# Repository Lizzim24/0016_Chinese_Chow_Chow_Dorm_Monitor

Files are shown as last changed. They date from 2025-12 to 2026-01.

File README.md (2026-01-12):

# Chinese Chow Chow Dorm Monitor

<p align="center">
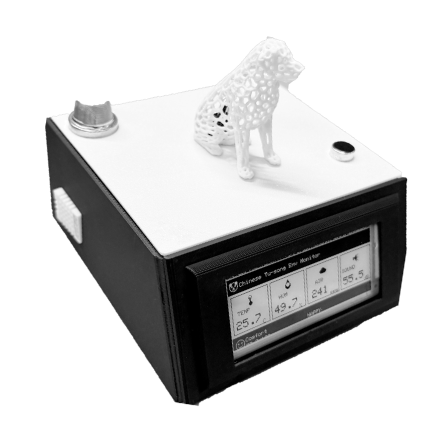
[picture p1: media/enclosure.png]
  <br>
  <em>Figure 1. The 3D-printed enclosure</em>
</p>

A biologically-informed IoT monitoring system designed for “Tu-song,” a Chow Chow living in a small student dormitory environment.  
The system monitors temperature, humidity, gases, and noise and computes a **breed-specific Comfort Index (CI)** for welfare assessment.

---

## 🐶 Why Chow Chow? Why Dorms?

Environmental monitors are typically designed for **humans**, but high-density indoor living poses unique physiological stressors for non-human inhabitants—especially double-coated, partially brachycephalic dogs such as the Chow Chow.

Chow Chows have:

- Dense double coat → high thermal sensitivity  
- Partial brachycephaly → airway restrictions under heat/humidity  
- Acute hearing → noise sensitivity in dorms  
- Sensitive skin → humidity + ammonia risk  

This project reframes environmental sensing around **species-specific comfort thresholds**, rather than generic human metrics.

---

## 🎯 Project Objectives

- Monitor key dorm environment variables  
- Map raw sensor data to a Comfort Index (CI)  
- Provide real-time feedback via LED + E-Paper  
- Detect hazard events (VOC, ammonia, noise spikes)  

---

## 🧩 System Architecture
<p align="center">
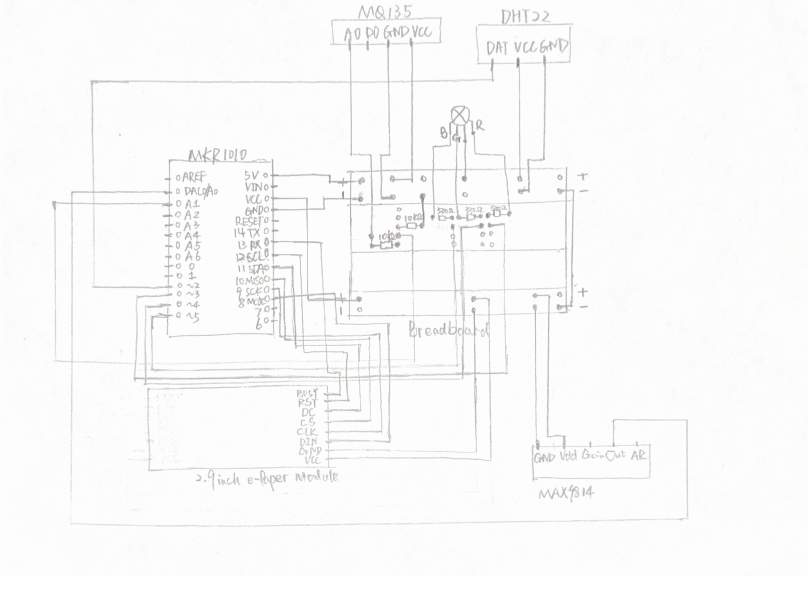
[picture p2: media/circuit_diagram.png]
  <br>
  <em>Figure 2. The whole circuit diagram. </em>
</p>
<p align="center">
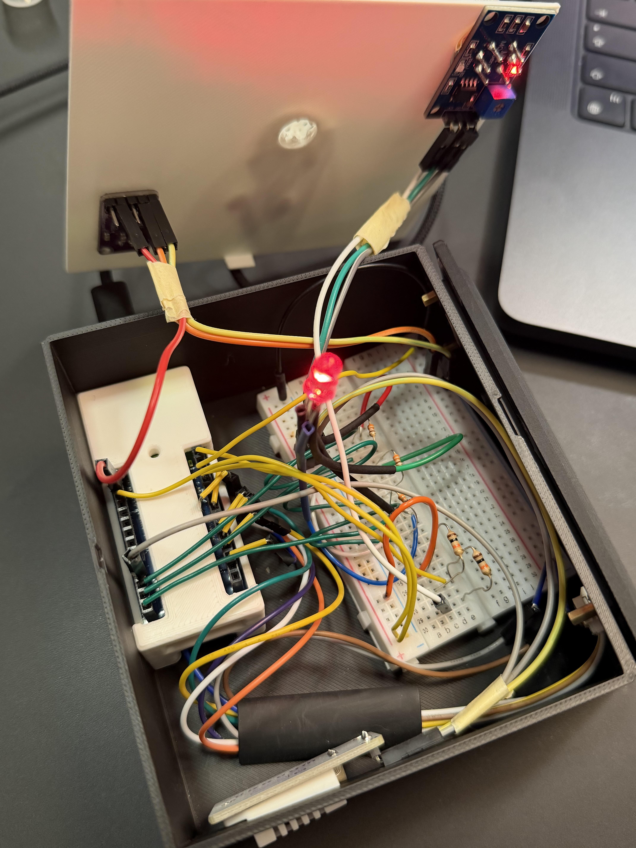
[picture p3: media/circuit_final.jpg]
  <br>
  <em>Figure 3. The actual circuit diagram. </em>
</p>

### Sensors & Biological Rationale

| Sensor | Parameter | Reason (Breed-Specific) |
| --- | --- | --- |
| DHT22 | Temp + Humidity | Thermal & skin sensitivity |
| MQ135 | VOC + Ammonia | Pet hygiene + respiratory irritation |
| MAX9814 | Noise level | Stress & acoustic sensitivity |
| E-Paper | Visual feedback | Zero light disturbance for the dog |
| MKR1010 | MCU + WiFi | Compute CI + future networking capability |

---

## 🔌 Hardware Design

- **MCU:** Arduino MKR WiFi 1010  
- **Gas:** MQ135 (5V) + voltage divider → 3.3V logic safe  
- **Acoustic:** MAX9814 w/ Auto Gain Control (AGC)  
- **Thermal:** DHT22 ±0.5 °C  
- **Display:** 2.9" E-Paper  
- **LED Feedback:** RGB real-time indicator  
- **Resistor:** Three 330Ω Resistors and two 10kΩ Resistors

Voltage protection implemented via:

$$ float voltage = (raw / 4095.0) * 3.3 * 2.0; $$

---

## 🧠 Comfort Index (CI) Model

The originality lies in the interpretive algorithm, not the raw sensing.

$$CI = 0.3·Temp + 0.3·Humidity + 0.2·Air + 0.2·Noise$$

Each dimension uses a trapezoidal mapping, for example:

- Optimal Zone (e.g., 15–22 °C) → score = 100  
- Warning Zone → linearly decreasing score  
- Danger Zone (e.g., > 28 °C) → score = 0

<p align="center">
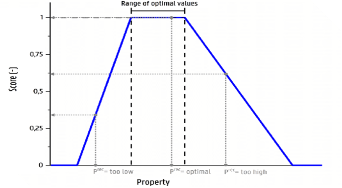
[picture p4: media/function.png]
  <br>
  <em>Figure 4. The trapezoidal mapping function.</em>
</p>
  
<p align="center">
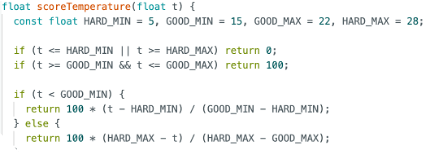
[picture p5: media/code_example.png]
  <br>
  <em>Figure 5. The temperature score code.</em>
</p>
---

## 🚨 Safety Override

A safety override loop runs independently of the 5-minute update cycle.

It triggers immediate alerts if:

- `NH₃ > 5 ppm` (from MQ135), or  
- `Noise > 75 dB` (from MAX9814)

When triggered:

- RGB LED is forced to **Red**  
- E-Paper display is forced to refresh  
- Critical hazards are shown even in low-power mode  

---

## 🖥 Dual Feedback Layers

### **1. Real-time RGB LED**
<p align="center">
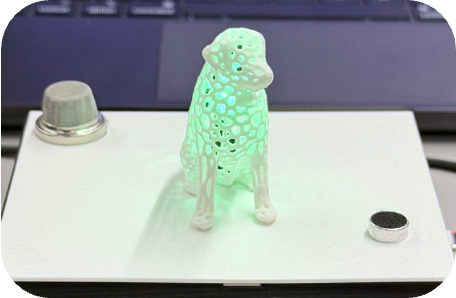
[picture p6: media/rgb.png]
  <br>
  <em>Figure 6. The RGB LED light.</em>
</p>

Color-coded welfare state:

- 🟢 Green — Comfortable & safe environment  
- 🟡 Yellow — Mild discomfort detected  
- 🔴 Red — Poor or hazardous environmental condition  

Includes:

- Auto-sleep logic to reduce disturbance during night  
- Still respects safety override for critical alerts  

### **2. E-Paper Display**
<p align="center">
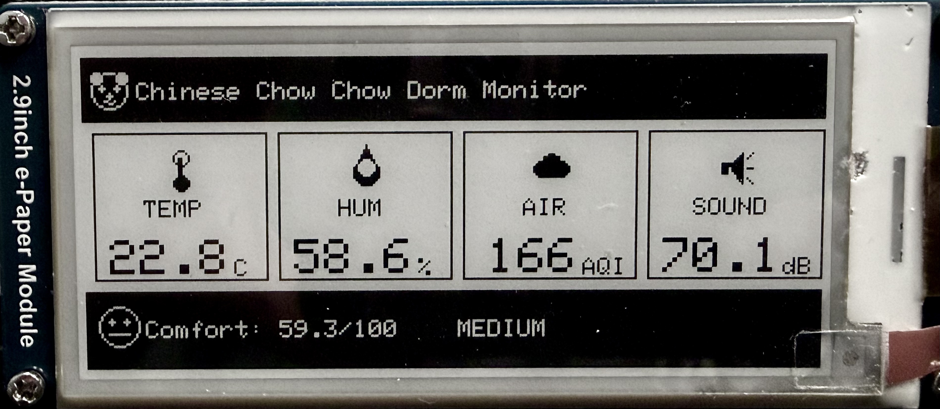
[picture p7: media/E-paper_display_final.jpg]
  <br>
  <em>Figure 7. The  e-paper interface.</em>
</p>

Hybrid refresh strategy:

- **Heartbeat Update:** Full refresh every 5 minutes  
- **Event-Triggered Update:** On significant changes  
  - e.g. Temp change > 0.5 °C, AQI change > 20  
- **Cooldown:** 30-second lockout to protect the screen  

This balances information freshness with power efficiency.

---

## 🏗 Physical Enclosure (Fusion 360)

<p align="center">
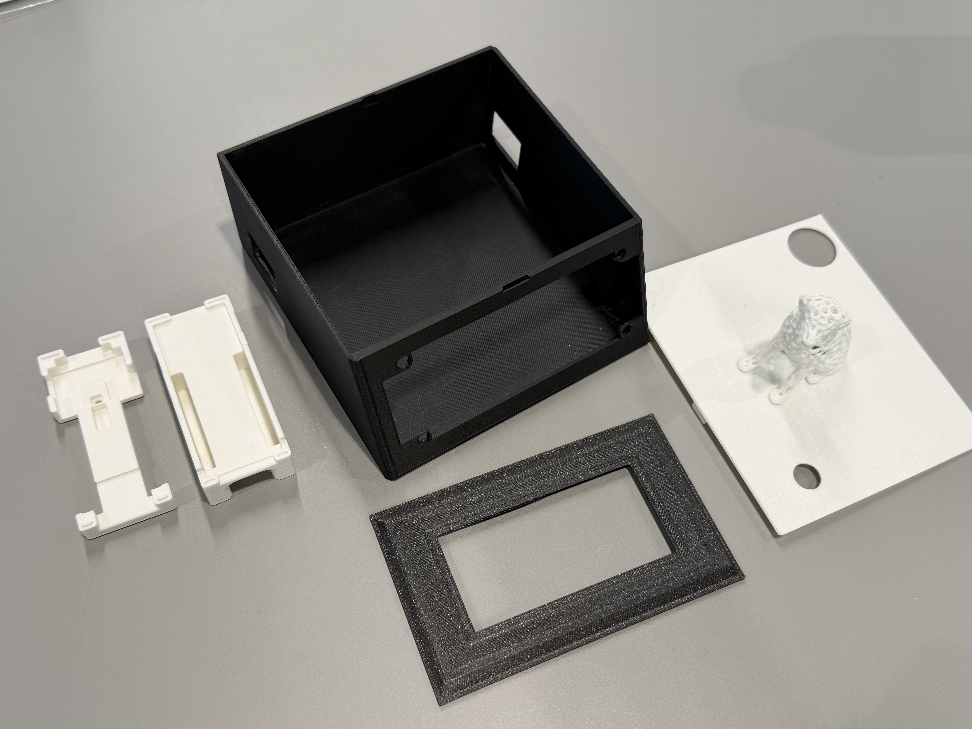
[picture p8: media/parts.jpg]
  <br>
  <em>Figure 8. All the parts of the enclosure design.</em>
</p>

The enclosure is designed with:

- Compact footprint suitable for a dorm room  
- Modular accessibility (removable top lid)  
- Dedicated cutouts for DHT22, MQ135, and MAX9814 so sensors can “see” the real environment  
- Front-facing E-Paper window for readability

<p align="center">
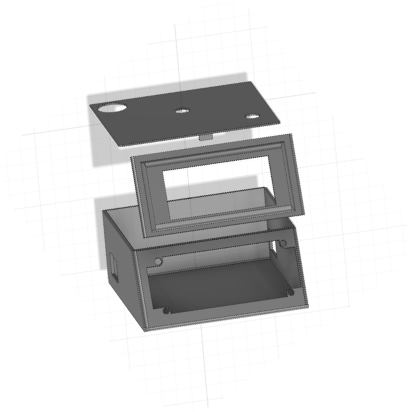
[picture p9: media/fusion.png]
  <br>
  <em>Figure 9. The parts that I designed.</em>
</p>

### **The Voronoi Dog Diffuser**

The visual centerpiece is a 3D-printed Voronoi Dog model (based on an open-source mesh by Kijai):

- The model is hollowed to house the RGB LED  
- The Voronoi pattern diffuses light into a soft glow  
- Avoids harsh LED glare and reduces light pollution at night
<p align="center">
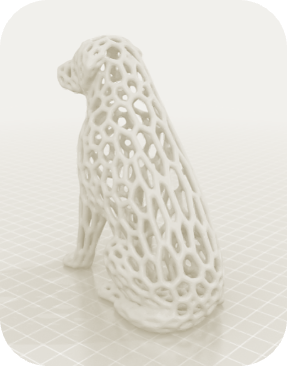
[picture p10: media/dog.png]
  <br>
  <em>Figure 10. The part that designed by Kijai.</em>
</p> 

### **The MKR 1010 Case**

- Portecting the arduino mkr wi-fi 1010 in my designed box.

<p align="center">
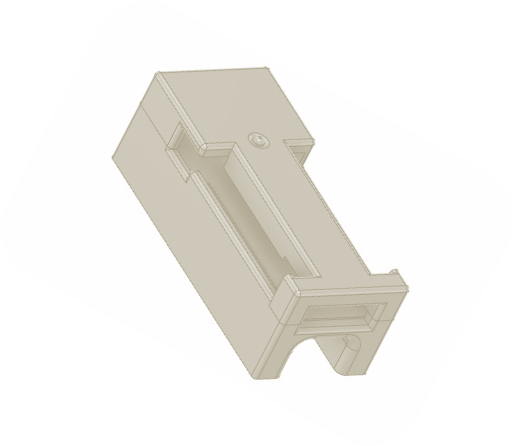
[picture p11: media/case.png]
  <br>
  <em>Figure 11. The part that designed by Piotr_W.</em>
</p> 
---

## 🧾 Evaluation

A 24-hour test in a ~20 m² student dorm showed:

- **14:00** – Direct sunlight raised temperature to ~25.5 °C → Yellow caution alert  
- **19:00** – Use of cleaning spray raised MQ135 reading to 256 ppm → Red “Dirty Air” alert  

These patterns suggest that:

- The CI mapping and thresholds respond realistically to dorm conditions  
- The system can detect and communicate real hazards relevant to a Chow Chow  

▶️ **Demo Video:** [https://youtu.be/xxxxxxx](https://youtu.be/MpVPKv-Cd-Y)

---

## ✅ Achievements & Limitations

### **Strengths**

- Breed-specific interpretation instead of generic “pet” logic  
- Trapezoidal Comfort Index algorithm implemented on MCU  
- E-Paper + Voronoi diffuser gives low-disturbance feedback  
- Custom Fusion 360 enclosure → functional + aesthetic  
- Thoughtful hardware protection (voltage divider, internal mounting)  

### **Limitations**

- MQ135 is an analog gas sensor → trend detection rather than absolute ppm accuracy  
- System is currently **monitor-only**; no active environmental control  
- MQ135 heater draws significant current → battery runtime constraints  

---

## 🚀 Future Roadmap

Planned/possible extensions:

- [ ] Add a relay-controlled fan for active ventilation  
- [ ] Integrate MQTT publishing and a remote Grafana dashboard  
- [ ] Introduce data logging for long-term comfort analysis  
- [ ] Explore CO₂ / NDIR sensors for better indoor air quality metrics  
- [ ] Power optimisation (duty-cycling, sensor sleep modes)  

---

## 🛠️ Tools & Technologies Used

### **Hardware & Prototyping**
- Arduino MKR WiFi 1010 (Cortex-M0+ MCU)
- DHT22 (Temperature & Humidity)
- MQ135 (VOC + Ammonia Gas Sensor)
- MAX9814 (AGC Microphone Module)
- 4-Pin RGB LED Indicator
- 2.9" E-Paper Display
- Breadboard + Jumper Wires + three 330Ω Resistors + two 10kΩ Resistors
- USB Power Supply

### **Software & Programming**
- Arduino IDE (Embedded C++)
- GxEPD2 (E-Paper Display Library)
- DHT Sensor Library
- Analog Signal Processing (MAX9814)
- Trapezoidal Mapping Algorithm (Custom)
- Safety Override Logic (Custom)

### **CAD & Manufacturing**
- Autodesk Fusion 360 (3D Design)
- FDM 3D Printing (Enclosure)
- PLA Filament (White & Black)
- Fusion STL Export → Slicing Pipeline

## 📚 References

- American Kennel Club (AKC) (2023) Chow Chow Dog Breed Information. Available at: https://www.akc.org/dog-breeds/chow-chow/ (Accessed: 10 January 2026).
- Analog Devices (n.d.) MAX9814: Microphone Amplifier with AGC and Low-Noise Microphone Bias. Available at: https://www.analog.com/media/en/technical- documentation/data-sheets/max9814.pdf (Accessed: 10 January 2026).
- Aosong Electronics (n.d.) Digital-output relative humidity & temperature sensor/module AM2302. Available at: https://www.mouser.com/datasheet/2/737/dht- 932870.pdf (Accessed: 5 January 2026).
- Arduino (2025) Arduino MKR Wi-Fi 1010 Documentation. Available at: https://docs.arduino.cc/hardware/mkr-wifi-1010/ (Accessed: 5 January 2026)
- Kijai (2021) Voronoi Dog. Available at: https://www.thingiverse.com/thing:4792489 (Accessed: 10 January 2026).
- Piotr_W (2021) Arduino MKR Wi-Fi 1010 case. Available at: https://www.thingiverse.com/thing:4818736 (Accessed: 10 January 2026).
- Waveshare (n.d.) 2.9inch e-Paper Datasheet. Available at: https://www.waveshare.com/wiki/File:2.9inch_e-Paper_Datasheet.pdf (Accessed: 10 January 2026).
- Winsen Sensor (2015) MQ135 Semiconductor Sensor for Hazardous Gas (Ver1.4). Available at: https://www.winsen-sensor.com/d/files/PDF/Semiconductor%20Gas%20Sensor/MQ135%20(Ver1.4)%20-%20Manual.pdf (Accessed: 10 January 2026).

## 🤖 Generative AI Use

This project used Generative AI tools (e.g. ChatGPT/Claude) in a supporting role for:

- Polishing English text (e.g. report sections, README)
- Translating mathematical ideas (trapezoidal mapping) into C++ pseudocode
- High-level debugging hints for Arduino libraries

All code and design decisions were:

- Manually validated against official datasheets
- Tested on hardware
- Owned and adapted by the author

The core concept, Comfort Index design, Fusion 360 enclosure, and full implementation were created by the author.

---
Personal Coursework for CASA0016 by Lizi

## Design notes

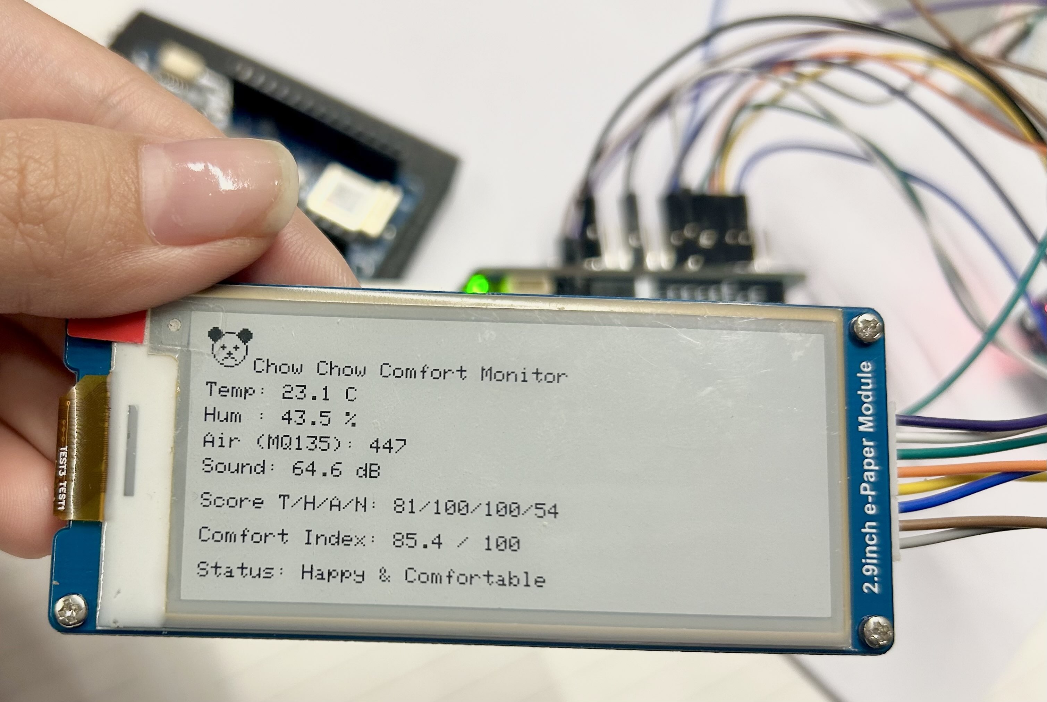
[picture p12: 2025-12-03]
media/E-paper_display_v1.jpg

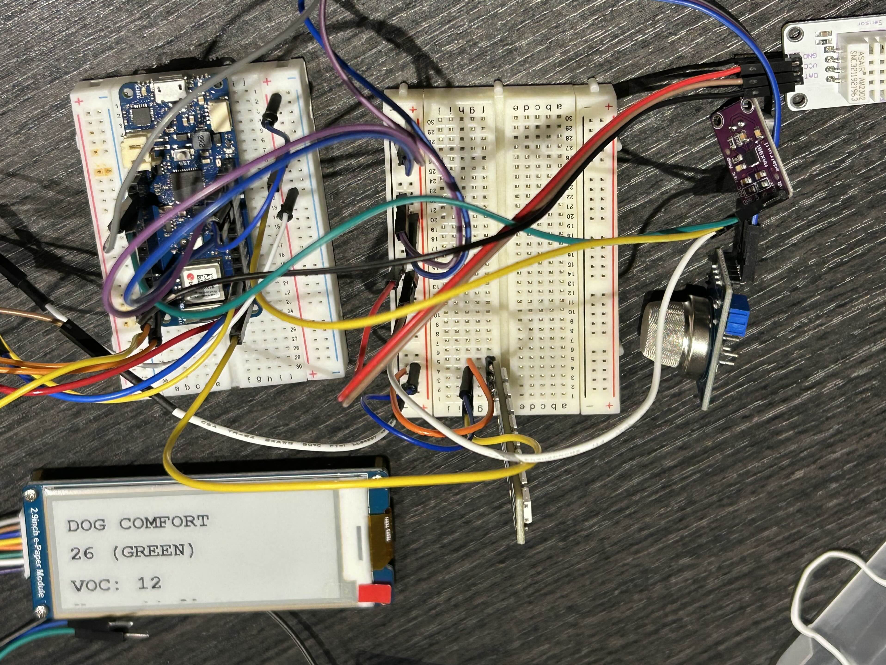
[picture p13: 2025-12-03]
media/circuit-v1.jpg

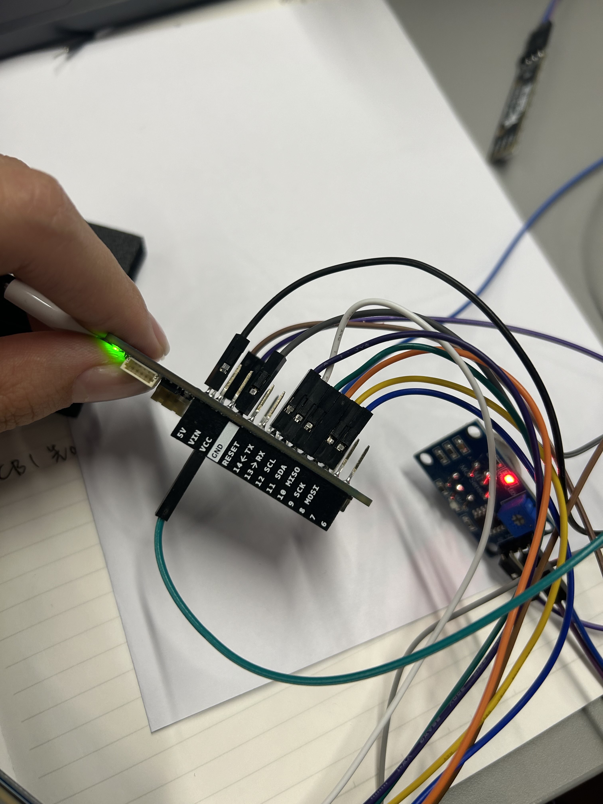
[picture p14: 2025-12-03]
media/circuit-v2.1.jpg

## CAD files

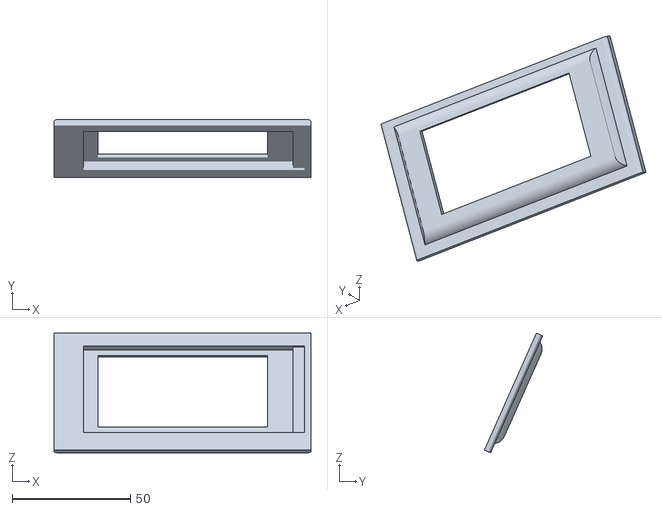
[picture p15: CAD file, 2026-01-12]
3D_model/mypj_cover.stl
108.6 x 24.7 x 50.6

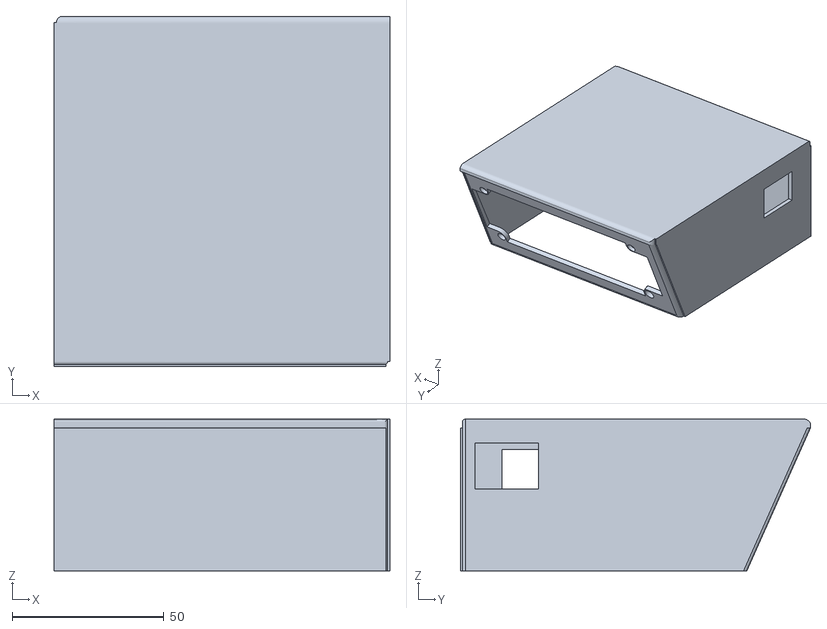
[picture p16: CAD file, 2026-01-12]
3D_model/mypj_v2botttom.stl
110.6 x 115.3 x 50.0

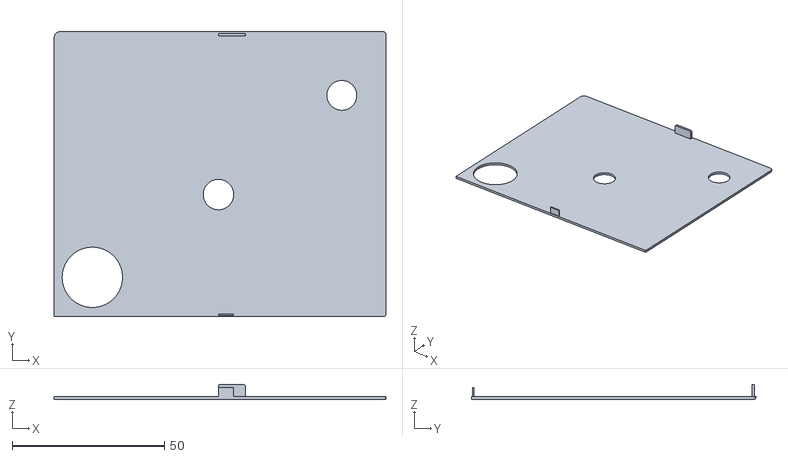
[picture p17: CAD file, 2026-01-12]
3D_model/mypj_v2lid.stl
109.0 x 93.5 x 5.00

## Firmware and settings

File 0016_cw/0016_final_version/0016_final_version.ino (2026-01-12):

#include "DHT.h"
#include <GxEPD2_BW.h>
#include <Adafruit_GFX.h>
#include <math.h>

#define PIN_MQ135 A1
#define PIN_SOUND A0
#define PIN_DHT 2
#define PIN_LED_R 3
#define PIN_LED_G 4
#define PIN_LED_B 5

#define EPAPER_CS 10
#define EPAPER_DC 11
#define EPAPER_RST 12
#define EPAPER_BUSY 13

#define DHTTYPE DHT22
DHT dht(PIN_DHT, DHTTYPE);

#define LED_SLEEP_AFTER_MS 30000UL
#define LED_MAX_VAL 200

const int RAW_QUIET = 1380;
const int RAW_LOUD = 1800;
const float DB_QUIET = 35.0;
const float DB_LOUD = 80.0;

#define RL_VALUE 10.0           
#define RO_CLEAN_AIR_FACTOR 3.6  
float MQ135_RO = 10.0;          

GxEPD2_BW<GxEPD2_290_T94, GxEPD2_290_T94::HEIGHT> display(
  GxEPD2_290_T94(EPAPER_CS, EPAPER_DC, EPAPER_RST, EPAPER_BUSY));

struct AirQualityData {
  int rawValue;
  int aqi;           
  float co2_ppm;     
  float nh3_ppm;     
  float score;       
  const char *level; 
  const char *color; 
};


struct SensorData {
  float temp;
  float humidity;
  AirQualityData airQuality;  
  float soundDB;
  float last_dB;

  float tempScore;
  float humScore;
  float airScore;
  float noiseScore;
  float comfortIndex;

  float lastTemp;
  float lastHum;
  int lastAQI;
  float lastComfort;
};

SensorData sensor = { 0 };

unsigned long lastSensorRead = 0;
unsigned long lastLedActiveTime = 0;
unsigned long lastEpaperUpdate = 0;

const unsigned long SENSOR_INTERVAL = 2000;
const unsigned long EPAPER_INTERVAL = 300000;
const unsigned long EPAPER_MIN_INTERVAL = 30000;

float mapFloat(float x, float in_min, float in_max, float out_min, float out_max) {
  return (x - in_min) * (out_max - out_min) / (in_max - in_min) + out_min;
}

float smooth(float prev, float cur, float alpha = 0.2) {
  return prev * (1.0 - alpha) + cur * alpha;
}

void calibrateMQ135() {
  Serial.println(F("\n╔════════════════════════════════════╗"));
  Serial.println(F("║   MQ135 Calibration Required      ║"));
  Serial.println(F("╠════════════════════════════════════╣"));
  Serial.println(F("║ Please ensure:                    ║"));
  Serial.println(F("║ 1. Windows are open               ║"));
  Serial.println(F("║ 2. Good ventilation               ║"));
  Serial.println(F("║ 3. No smoking/cooking nearby      ║"));
  Serial.println(F("╚════════════════════════════════════╝"));
  Serial.println(F("Calibrating in 10 seconds..."));

  for (int i = 10; i > 0; i--) {
    Serial.print(i);
    Serial.print("... ");
    delay(1000);
  }
  Serial.println(F("\nCalibrating (sampling 50 times)..."));

  float rsSum = 0;
  for (int i = 0; i < 50; i++) {
    int raw = analogRead(PIN_MQ135);
    float voltage = (raw / 4095.0) * 3.3 * 2.0;
    if (voltage < 0.01) voltage = 0.01;
    float rs = ((3.3 - voltage) / voltage) * RL_VALUE;
    rsSum += rs;
    delay(100);

    if (i % 10 == 0) {
      Serial.print(".");
    }
  }

  float avgRS = rsSum / 50.0;
  MQ135_RO = avgRS / RO_CLEAN_AIR_FACTOR;

  Serial.println();
  Serial.print(F("✓ Calibration complete! RO = "));
  Serial.print(MQ135_RO, 2);
  Serial.println(F(" kΩ"));
  Serial.println(F("═══════════════════════════════════\n"));
}

AirQualityData readMQ135_Enhanced() {
  AirQualityData result;
  result.rawValue = analogRead(PIN_MQ135);

  float voltage = (result.rawValue / 4095.0) * 3.3 * 2.0;
  if (voltage < 0.01) voltage = 0.01;

  float rs = ((3.3 - voltage) / voltage) * RL_VALUE;
  float ratio = rs / MQ135_RO;  // Rs/Ro

  result.co2_ppm = 116.6 * pow(ratio, -2.6);
  result.co2_ppm = constrain(result.co2_ppm, 300, 5000);

  result.nh3_ppm = 102.2 * pow(ratio, -2.47);

  if (result.nh3_ppm < 0.1) result.nh3_ppm = 0.1;
  result.nh3_ppm = constrain(result.nh3_ppm, 0.1, 100.0);

  float targetGas = result.nh3_ppm;

  if (targetGas < 1.0) {
    result.aqi = mapFloat(targetGas, 0.1, 1.0, 0, 50);
    result.level = "Clean";
    result.color = "Green"; 
  } else if (targetGas < 3.0) {
    result.aqi = mapFloat(targetGas, 1.0, 3.0, 51, 100);
    result.level = "Scented"; 
    result.color = "Yellow"; 
  } else if (targetGas < 5.0) {
    result.aqi = mapFloat(targetGas, 3.0, 5.0, 101, 200);
    result.level = "Dirty";
    result.color = "Orange";  
  } else {
    result.aqi = mapFloat(targetGas, 5.0, 20.0, 201, 500);
    result.aqi = constrain(result.aqi, 201, 500);
    result.level = "Toxic";
    result.color = "Red";
  }

  if (result.aqi <= 50) {
    result.score = 100;
  } else {
    result.score = max(0.0, 100.0 - (result.aqi - 50.0) * 0.8);
  }

  return result;
}

float readSound_dB() {
  int raw = analogRead(PIN_SOUND);
  raw = constrain(raw, RAW_QUIET, RAW_LOUD);

  float db = mapFloat((float)raw, (float)RAW_QUIET, (float)RAW_LOUD,
                      DB_QUIET, DB_LOUD);

  sensor.last_dB = smooth(sensor.last_dB, db, 0.2);
  return sensor.last_dB;
}

bool readDHT22(float &temp, float &hum) {
  temp = dht.readTemperature();
  hum = dht.readHumidity();

  if (isnan(temp) || isnan(hum)) {
    Serial.println(F("DHT22 read failed!"));
    return false;
  }
  return true;
}

float scoreTemperature(float t) {
  const float HARD_MIN = 5, GOOD_MIN = 15, GOOD_MAX = 22, HARD_MAX = 28;

  if (t <= HARD_MIN || t >= HARD_MAX) return 0;
  if (t >= GOOD_MIN && t <= GOOD_MAX) return 100;

  if (t < GOOD_MIN) {
    return 100 * (t - HARD_MIN) / (GOOD_MIN - HARD_MIN);
  } else {
    return 100 * (HARD_MAX - t) / (HARD_MAX - GOOD_MAX);
  }
}

float scoreHumidity(float h) {
  const float HARD_MIN = 20, GOOD_MIN = 40, GOOD_MAX = 55, HARD_MAX = 75;

  if (h <= HARD_MIN || h >= HARD_MAX) return 0;
  if (h >= GOOD_MIN && h <= GOOD_MAX) return 100;

  if (h < GOOD_MIN) {
    return 100 * (h - HARD_MIN) / (GOOD_MIN - HARD_MIN);
  } else {
    return 100 * (HARD_MAX - h) / (HARD_MAX - GOOD_MAX);
  }
}

float noiseComfortScore(float dB) {
  if (dB <= 45) return 100;
  if (dB >= 80) return 0;

  if (dB <= 60) {
    return 100 - (dB - 45) / 15.0 * 30;
  } else if (dB <= 75) {
    return 70 - (dB - 60) / 15.0 * 50;
  } else {
    return 20 - (dB - 75) / 5.0 * 20;
  }
}

float computeComfortIndex(float tempScore, float humScore,
                          float airScore, float noiseScore) {
  return 0.30 * tempScore + 0.30 * humScore + 0.20 * airScore + 0.20 * noiseScore;
}

void setRGB(uint8_t r, uint8_t g, uint8_t b) {
  r = constrain(r, 0, LED_MAX_VAL);
  g = constrain(g, 0, LED_MAX_VAL);
  b = constrain(b, 0, LED_MAX_VAL);

  float scale = 255.0 / LED_MAX_VAL;

  analogWrite(PIN_LED_R, 255 - (uint8_t)(r * scale));
  analogWrite(PIN_LED_G, 255 - (uint8_t)(g * scale));
  analogWrite(PIN_LED_B, 255 - (uint8_t)(b * scale));
}

void showComfortRGB(float comfort) {
  uint8_t r = 0, g = 0, b = 0;

  if (comfort >= 70) {
    g = LED_MAX_VAL;
  } else if (comfort >= 40) {
    r = LED_MAX_VAL;
    g = (uint8_t)(LED_MAX_VAL * 0.7);
  } else {
    r = LED_MAX_VAL;
  }

  setRGB(r, g, b);
  lastLedActiveTime = millis();
}

void turnOffRGB() {
  setRGB(0, 0, 0);
}

void drawDogIcon(int16_t x, int16_t y) {
  int16_t cx = x + 8, cy = y + 8;
  display.drawCircle(cx, cy, 7, GxEPD_WHITE);
  display.fillCircle(cx - 5, cy - 5, 2, GxEPD_WHITE);
  display.fillCircle(cx + 5, cy - 5, 2, GxEPD_WHITE);
  display.fillCircle(cx - 3, cy - 1, 1, GxEPD_WHITE);
  display.fillCircle(cx + 3, cy - 1, 1, GxEPD_WHITE);
  display.fillCircle(cx, cy + 2, 1, GxEPD_WHITE);
  display.drawLine(cx - 2, cy + 4, cx, cy + 5, GxEPD_WHITE);
  display.drawLine(cx, cy + 5, cx + 2, cy + 4, GxEPD_WHITE);
}

void drawTempIcon(int16_t x, int16_t y) {
  display.fillCircle(x + 10, y + 15, 3, GxEPD_BLACK);
  display.fillRect(x + 9, y + 5, 2, 10, GxEPD_BLACK);
  display.drawCircle(x + 10, y + 5, 3, GxEPD_BLACK);
}

void drawHumidityIcon(int16_t x, int16_t y) {
  display.fillTriangle(x + 10, y + 2, x + 5, y + 12, x + 15, y + 12, GxEPD_BLACK);
  display.fillCircle(x + 10, y + 13, 5, GxEPD_BLACK);
  display.fillCircle(x + 10, y + 11, 3, GxEPD_WHITE);
}

void drawAirIcon(int16_t x, int16_t y) {
  display.fillCircle(x + 6, y + 10, 3, GxEPD_BLACK);
  display.fillCircle(x + 10, y + 8, 4, GxEPD_BLACK);
  display.fillCircle(x + 14, y + 10, 3, GxEPD_BLACK);
  display.fillRect(x + 6, y + 10, 8, 4, GxEPD_BLACK);
}

void drawSoundIcon(int16_t x, int16_t y) {
  display.fillRect(x + 4, y + 8, 3, 5, GxEPD_BLACK);
  display.fillTriangle(x + 7, y + 8, x + 12, y + 4, x + 12, y + 16, GxEPD_BLACK);
  display.drawLine(x + 14, y + 6, x + 16, y + 4, GxEPD_BLACK);
  display.drawLine(x + 14, y + 10, x + 16, y + 10, GxEPD_BLACK);
  display.drawLine(x + 14, y + 14, x + 16, y + 16, GxEPD_BLACK);
}

void drawComfortFace(int16_t x, int16_t y, float comfort) {
  int16_t cx = x + 9, cy = y + 9;

  display.drawCircle(cx, cy, 8, GxEPD_WHITE);
  display.fillCircle(cx - 3, cy - 2, 1, GxEPD_WHITE);
  display.fillCircle(cx + 3, cy - 2, 1, GxEPD_WHITE);

  if (comfort >= 70) {
    display.drawLine(cx - 4, cy + 2, cx - 2, cy + 4, GxEPD_WHITE);
    display.drawLine(cx - 2, cy + 4, cx + 2, cy + 4, GxEPD_WHITE);
    display.drawLine(cx + 2, cy + 4, cx + 4, cy + 2, GxEPD_WHITE);
  } else if (comfort >= 40) {
    display.drawLine(cx - 4, cy + 3, cx + 4, cy + 3, GxEPD_WHITE);
  } else {
    display.drawLine(cx - 4, cy + 5, cx - 2, cy + 3, GxEPD_WHITE);
    display.drawLine(cx - 2, cy + 3, cx + 2, cy + 3, GxEPD_WHITE);
    display.drawLine(cx + 2, cy + 3, cx + 4, cy + 5, GxEPD_WHITE);
  }
}

void epaperShowStatus(const SensorData &data) {
  display.setFullWindow();
  display.clearScreen();
  delay(100);

  display.firstPage();

  do {
    display.fillScreen(GxEPD_WHITE);

    display.fillRect(0, 0, 296, 2, GxEPD_WHITE);
    display.fillRect(0, 2, 296, 26, GxEPD_BLACK);
    drawDogIcon(3, 7);
    display.setTextColor(GxEPD_WHITE);
    display.setTextSize(1);
    display.setCursor(22, 12);
    display.println("Chinese Chow Chow Dorm Monitor");
    display.setTextColor(GxEPD_BLACK);

    int cardY = 32;
    int cardH = 60;
    int cardW = 70;
    int spacing = 4;
    int startX = 4;

    int card1X = startX;
    display.drawRect(card1X, cardY, cardW, cardH, GxEPD_BLACK);
    drawTempIcon(card1X + 25, cardY + 5);
    display.setCursor(card1X + 20, cardY + 27);
    display.println("TEMP");
    display.setCursor(card1X + 6, cardY + 43);
    display.setTextSize(2);
    display.print(data.temp, 1);
    display.setTextSize(1);
    display.setCursor(card1X + cardW - 14, cardY + cardH - 9);
    display.println("C");

    int card2X = card1X + cardW + spacing;
    display.drawRect(card2X, cardY, cardW, cardH, GxEPD_BLACK);
    drawHumidityIcon(card2X + 25, cardY + 3);
    display.setCursor(card2X + 24, cardY + 27);
    display.println("HUM");
    display.setCursor(card2X + 6, cardY + 43);
    display.setTextSize(2);
    display.print(data.humidity, 1);
    display.setTextSize(1);
    display.setCursor(card2X + cardW - 14, cardY + cardH - 9);
    display.println("%");

    int card3X = card2X + cardW + spacing;
    display.drawRect(card3X, cardY, cardW, cardH, GxEPD_BLACK);
    drawAirIcon(card3X + 25, cardY + 5);
    display.setCursor(card3X + 24, cardY + 27);
    display.println("AIR");
    display.setCursor(card3X + 10, cardY + 43);
    display.setTextSize(2);
    display.println(data.airQuality.aqi);
    display.setTextSize(1);
    display.setCursor(card3X + cardW - 22, cardY + cardH - 9);
    display.println("AQI");

    int card4X = card3X + cardW + spacing;
    display.drawRect(card4X, cardY, cardW, cardH, GxEPD_BLACK);
    drawSoundIcon(card4X + 25, cardY + 5);
    display.setCursor(card4X + 18, cardY + 27);
    display.println("SOUND");
    display.setCursor(card4X + 6, cardY + 43);
    display.setTextSize(2);
    display.print(data.soundDB, 1);
    display.setTextSize(1);
    display.setCursor(card4X + cardW - 16, cardY + cardH - 9);
    display.println("dB");

    int bottomY = 96;
    int bottomH = 32;
    display.fillRect(0, bottomY, 296, bottomH, GxEPD_BLACK);
    display.setTextColor(GxEPD_WHITE);

    drawComfortFace(4, bottomY + 5, data.comfortIndex);

    display.setCursor(24, bottomY + 12);
    display.println("Comfort: ");
    display.setCursor(78, bottomY + 12);
    display.print(data.comfortIndex, 1);
    display.print("/100");

    const char *statusText;
    if (data.comfortIndex >= 70) {
      statusText = "HAPPY & Comfortable";
    } else if (data.comfortIndex >= 40) {
      statusText = "MEDIUM";
    } else {
      statusText = "BAD";
    }

    display.setCursor(150, bottomY + 12);
    display.println(statusText);

    display.setTextColor(GxEPD_BLACK);

  } while (display.nextPage());

  Serial.println(F("✓ E-Paper updated"));
}

void updateLastValues(SensorData &data) {
  data.lastTemp = data.temp;
  data.lastHum = data.humidity;
  data.lastAQI = data.airQuality.aqi;
  data.lastComfort = data.comfortIndex;
}

bool hasSignificantChange(const SensorData &data) {
  bool tempChanged = fabs(data.temp - data.lastTemp) > 0.5;
  bool humChanged = fabs(data.humidity - data.lastHum) > 3.0;
  bool airChanged = abs(data.airQuality.aqi - data.lastAQI) > 20;
  bool comfortChanged = fabs(data.comfortIndex - data.lastComfort) > 5.0;

  return tempChanged || humChanged || airChanged || comfortChanged;
}

void printSmartSuggestions(const SensorData &data) {
  bool hasSuggestion = false;

  Serial.println(F("─────────────────────────────────"));
  Serial.println(F("💡 Smart Suggestions (Chow-Specific):"));

  if (data.airQuality.nh3_ppm > 5.0) {
    Serial.println(F("  ⚠️ TOXIC AIR! Ammonia/Chemicals high. Evacuate pet!"));
    hasSuggestion = true;
  } else if (data.airQuality.nh3_ppm > 3.0) {
    Serial.println(F("  🧹 Strong Odor! Check litter box or reduce air freshener."));
    hasSuggestion = true;
  } else if (data.airQuality.nh3_ppm > 1.0) {
    Serial.println(F("  💨 Ventilation needed. Air is stale/scented."));
    hasSuggestion = true;
  }

  if (data.temp < 15) {
    Serial.println(F("  🌡️  Too cold! Turn on heating."));
    hasSuggestion = true;
  } else if (data.temp > 24) {
    Serial.println(F("  ❄️  Too hot! Turn on cooling or fan."));
    hasSuggestion = true;
  }

  if (data.humidity < 35) {
    Serial.println(F("  💧 Too dry! Use humidifier."));
    hasSuggestion = true;
  } else if (data.humidity > 60) {
    Serial.println(F("  💨 Too humid! Use dehumidifier or ventilate."));
    hasSuggestion = true;
  }

  if (data.soundDB > 65) {
    Serial.println(F("  🔇 Noise level high! Check for disturbances."));
    hasSuggestion = true;
  }

  if (!hasSuggestion) {
    Serial.println(F("  ✓ Environment is perfect for your Chow Chow."));
  }
  Serial.println(F("─────────────────────────────────"));
}

void setup() {
  Serial.begin(115200);
  while (!Serial && millis() < 3000) {}

  Serial.println(F("\n╔════════════════════════════════════╗"));
  Serial.println(F("║ Chinese Chow Chow Comfort Monitor ║"));
  Serial.println(F("║           Version 4.0              ║"));
  Serial.println(F("║   Enhanced Air Quality Edition     ║"));
  Serial.println(F("╚════════════════════════════════════╝\n"));

  analogReadResolution(12);
  dht.begin();

  pinMode(PIN_LED_R, OUTPUT);
  pinMode(PIN_LED_G, OUTPUT);
  pinMode(PIN_LED_B, OUTPUT);
  turnOffRGB();

  display.init(115200);
  display.setRotation(1);
  display.setTextColor(GxEPD_BLACK);

  Serial.println(F("Initializing MQ135 sensor..."));
  Serial.println(F("⚠️  IMPORTANT: Sensor needs 24-48h preheat for best accuracy"));
  Serial.println(F("For quick start, we'll calibrate now (less accurate)"));
  Serial.print(F("Skip calibration? (Sensor must be in clean air) [Y/N]: "));

  unsigned long waitStart = millis();
  bool skipCalib = false;
  while (millis() - waitStart < 5000) {
    if (Serial.available()) {
      char c = Serial.read();
      if (c == 'Y' || c == 'y') {
        skipCalib = true;
        Serial.println(F("Y - Skipped"));
        Serial.println(F("Using default RO = 10.0 kΩ"));
        break;
      }
    }
  }

  if (!skipCalib) {
    Serial.println(F("N - Starting calibration..."));
    calibrateMQ135();
  }

  Serial.println(F("\n✓ System initialized!\n"));

  if (readDHT22(sensor.temp, sensor.humidity)) {
    sensor.airQuality = readMQ135_Enhanced();
    sensor.soundDB = readSound_dB();
    sensor.tempScore = scoreTemperature(sensor.temp);
    sensor.humScore = scoreHumidity(sensor.humidity);
    sensor.airScore = sensor.airQuality.score;
    sensor.noiseScore = noiseComfortScore(sensor.soundDB);
    sensor.comfortIndex = computeComfortIndex(sensor.tempScore,
                                              sensor.humScore,
                                              sensor.airScore,
                                              sensor.noiseScore);
    updateLastValues(sensor);
    epaperShowStatus(sensor);
    showComfortRGB(sensor.comfortIndex);
  }
}

void loop() {
  unsigned long now = millis();

  if (now - lastLedActiveTime > LED_SLEEP_AFTER_MS) {
    turnOffRGB();
  }

  if (now - lastSensorRead >= SENSOR_INTERVAL) {
    lastSensorRead = now;

    if (!readDHT22(sensor.temp, sensor.humidity)) {
      sensor.temp = sensor.lastTemp;
      sensor.humidity = sensor.lastHum;
    }

    sensor.airQuality = readMQ135_Enhanced();
    sensor.soundDB = readSound_dB();

    sensor.tempScore = scoreTemperature(sensor.temp);
    sensor.humScore = scoreHumidity(sensor.humidity);
    sensor.airScore = sensor.airQuality.score;
    sensor.noiseScore = noiseComfortScore(sensor.soundDB);
    sensor.comfortIndex = computeComfortIndex(sensor.tempScore,
                                              sensor.humScore,
                                              sensor.airScore,
                                              sensor.noiseScore);


    bool isEmergency = false;

    if (sensor.airQuality.nh3_ppm > 5.0) {
      isEmergency = true;
      Serial.println(F("🚨 ALERT: High Ammonia detected! Overriding status to RED."));
    }

    if (sensor.soundDB > 75) {
      isEmergency = true;
      Serial.println(F("🚨 ALERT: Extreme Noise! Overriding status to RED."));
    }

    float voltage = (analogRead(PIN_MQ135) / 4095.0) * 3.3 * 2.0;

    Serial.print("DEBUG VOLTAGE: ");
    Serial.println(voltage);

    Serial.println(F("\n╔═══════════════════════════════════╗"));
    Serial.println(F("║     ENVIRONMENT MONITORING        ║"));
    Serial.println(F("╠═══════════════════════════════════╣"));

    Serial.print(F("║ Temperature:  "));
    Serial.print(sensor.temp, 1);
    Serial.print(F("°C"));
    Serial.print(F("  (Score: "));
    Serial.print(sensor.tempScore, 0);
    Serial.println(F(")    ║"));

    Serial.print(F("║ Humidity:     "));
    Serial.print(sensor.humidity, 1);
    Serial.print(F("%"));
    Serial.print(F("   (Score: "));
    Serial.print(sensor.humScore, 0);
    Serial.println(F(")    ║"));

    Serial.println(F("╠═══════════════════════════════════╣"));
    Serial.print(F("║ Air Quality:  AQI "));
    Serial.print(sensor.airQuality.aqi);
    Serial.print(F(" ("));
    Serial.print(sensor.airQuality.level);
    Serial.println(F(")  ║"));

    Serial.print(F("║   └─ CO₂:     "));
    Serial.print(sensor.airQuality.co2_ppm, 0);
    Serial.println(F(" ppm           ║"));

    Serial.print(F("║   └─ NH₃:     "));
    Serial.print(sensor.airQuality.nh3_ppm, 1);
    Serial.println(F(" ppm (Pet)      ║"));

    Serial.print(F("║   └─ Score:   "));
    Serial.print(sensor.airScore, 0);
    Serial.println(F(" / 100          ║"));

    Serial.println(F("╠═══════════════════════════════════╣"));
    Serial.print(F("║ Sound Level:  "));
    Serial.print(sensor.soundDB, 1);
    Serial.print(F(" dB"));
    Serial.print(F("  (Score: "));
    Serial.print(sensor.noiseScore, 0);
    Serial.println(F(") ║"));

    Serial.println(F("╠═══════════════════════════════════╣"));
    Serial.print(F("║ COMFORT INDEX: "));
    Serial.print(sensor.comfortIndex, 1);
    Serial.print(F(" / 100"));

    if (sensor.comfortIndex >= 70) {
      Serial.println(F("  ✓     ║"));
    } else if (sensor.comfortIndex >= 40) {
      Serial.println(F("  ~     ║"));
    } else {
      Serial.println(F("  ✗     ║"));
    }

    Serial.println(F("╚═══════════════════════════════════╝"));

    printSmartSuggestions(sensor);

    unsigned long timeSinceLastUpdate = now - lastEpaperUpdate;
    bool hasChanged = hasSignificantChange(sensor);
    bool timeForScheduledUpdate = (timeSinceLastUpdate >= EPAPER_INTERVAL);
    bool cooledDown = (timeSinceLastUpdate >= EPAPER_MIN_INTERVAL);

    if (hasChanged) {
      showComfortRGB(sensor.comfortIndex); 
      Serial.println(F("🔔 Change detected! LED Activated."));
    }

    if (isEmergency) {
      setRGB(200, 0, 0);
      lastLedActiveTime = millis(); 
    } else if (hasChanged) {
      showComfortRGB(sensor.comfortIndex);
    }

    if (timeForScheduledUpdate || (hasChanged && cooledDown)) {
      if (hasChanged && !timeForScheduledUpdate) {
        Serial.println(F("📊 Significant change detected, updating display..."));
      } else {
        Serial.println(F("⏰ Scheduled display update..."));
      }

      epaperShowStatus(sensor);
      updateLastValues(sensor);
      lastEpaperUpdate = now;
    } else if (hasChanged && !cooledDown) {
      Serial.print(F("⏳ Change detected but cooling down... "));
      Serial.print((EPAPER_MIN_INTERVAL - timeSinceLastUpdate) / 1000);
      Serial.println(F("s remaining"));
    }
  }

  delay(100);
}

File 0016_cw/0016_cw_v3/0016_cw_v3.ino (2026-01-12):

/****************************************************
 * Chow Chow Comfort Monitor - MKR WiFi 1010 Version V3
 * 板子：Arduino MKR WiFi 1010（3.3V 逻辑）
 * 传感器：MQ135 + DHT22 + MAX9814 + Neopixel(8) + 2.9" e-paper (296x128)
 *
 * 保护点：
 *  - Neopixel 全局限亮度 MAX_BRIGHTNESS
 *  - 显示逻辑避免全白全亮，只用偏暗的红/黄/绿
 *  - 自动熄灯（LED_SLEEP_AFTER_MS）降低平均电流
 *  - MAX9814 用 3.3V 供电
 *  - 所有模拟输入使用 analogReadResolution(12)（0~4095）
 ****************************************************/

#include <Adafruit_NeoPixel.h>
#include "DHT.h"

#include <GxEPD2_BW.h>
#include <Adafruit_GFX.h>

// ================= 引脚定义 =================
// 模拟输入
#define PIN_MQ135 A1  // MQ135 模拟输出
#define PIN_SOUND A0  // MAX9814 模拟输出

// 数字 IO
#define PIN_DHT 2       // DHT22 数据脚
#define PIN_NEOPIXEL 6  // Neopixel DIN

// e-paper SPI 控制脚（MKR 的 SPI SCK/MOSI 走板子上的专用 SPI 引脚）
#define EPAPER_CS 10
#define EPAPER_DC 11
#define EPAPER_RST 12
#define EPAPER_BUSY 13

// ================= DHT 配置 =================
#define DHTTYPE DHT22
DHT dht(PIN_DHT, DHTTYPE);

// ================= Neopixel 配置 =================
#define NUM_PIXELS 8
#define MAX_BRIGHTNESS 40           // 电流保护：0~255，建议 20~60
#define LED_SLEEP_AFTER_MS 30000UL  // 30s 无更新则自动熄灯

Adafruit_NeoPixel strip(NUM_PIXELS, PIN_NEOPIXEL, NEO_GRB + NEO_KHZ800);

// ================= MAX9814 声音 → dB 映射配置 =================
// 这些值来自你之前在 MKR1010 上测试的 raw 范围（12bit ADC 0~4095）
// 可以根据实际宿舍环境再微调
int RAW_QUIET = 1380;  // 宿舍安静时的 analogRead(A0)
int RAW_LOUD = 1800;   // 有人说话/稍吵时 analogRead(A0)

// 映射到的 dB 范围（参考宠物噪音阈值）
float DB_QUIET = 35.0;  // 安静房间约 35 dB
float DB_LOUD = 80.0;   // 比较吵的环境约 80 dB

float last_dB = 40.0;  // 用于平滑滤波的上一帧 dB

// ================= e-paper 显示配置 =================
// 这里假设你的 2.9" 296x128 屏是 GxEPD2_290_T94 型号
// 如果编译报错，请去 GxEPD2 示例中确认正确的类名替换这一行
GxEPD2_BW<GxEPD2_290_T94, GxEPD2_290_T94::HEIGHT> display(
  GxEPD2_290_T94(EPAPER_CS, EPAPER_DC, EPAPER_RST, EPAPER_BUSY));

// ================= 全局变量 =================
unsigned long lastSensorRead = 0;
unsigned long sensorInterval = 2000;  // 每 2 秒更新一次传感器
unsigned long lastLedActiveTime = 0;

float lastTemp = 0;
float lastHum = 0;
int lastMQ135 = 0;

// ================= 工具函数 =================

// 浮点映射
float mapFloat(float x, float in_min, float in_max, float out_min, float out_max) {
  return (x - in_min) * (out_max - out_min) / (in_max - in_min) + out_min;
}

// 简单平滑滤波
float smooth(float prev, float cur, float alpha = 0.2) {
  return prev * (1 - alpha) + cur * alpha;
}

// ========== 1. 声音：MAX9814 → dB → 噪音舒适度评分 ==========

// 读取声传感器原始值，并映射到大约 35~80 dB
float readSound_dB() {
  int raw = analogRead(PIN_SOUND);

  // 限制范围，去掉极端异常值
  raw = constrain(raw, RAW_QUIET, RAW_LOUD);

  // 映射到 dB
  float db = mapFloat((float)raw, (float)RAW_QUIET, (float)RAW_LOUD,
                      DB_QUIET, DB_LOUD);

  // 平滑一下，让变化不要太跳
  last_dB = smooth(last_dB, db, 0.2);

  return last_dB;
}

// 噪音舒适度：0~100（越高越舒适）
float noiseComfortScore(float dB) {
  if (dB <= 45) return 100;  // 非常安静
  if (dB >= 80) return 0;    // 非常吵

  if (dB <= 60) {
    // 45 → 60 dB：舒适度从 100 降到 70
    float ratio = (dB - 45) / (60 - 45);
    return 100 - ratio * 30;  // 100 → 70
  } else if (dB <= 75) {
    // 60 → 75 dB：舒适度从 70 降到 20
    float ratio = (dB - 60) / (75 - 60);
    return 70 - ratio * 50;  // 70 → 20
  } else {
    // 75 → 80 dB：20 → 0
    float ratio = (dB - 75) / (80 - 75);
    return 20 - ratio * 20;  // 20 → 0
  }
}

// ========== 2. 温度 / 湿度 / 空气质量评分（0~100） ==========

// 温度舒适度：松狮犬 15–22°C 最佳，22–25 还行，>26 不适
float scoreTemperature(float t) {
  const float HARD_MIN = 5;
  const float GOOD_MIN = 15;
  const float GOOD_MAX = 22;
  const float HARD_MAX = 28;

  if (t <= HARD_MIN || t >= HARD_MAX) return 0;
  if (t >= GOOD_MIN && t <= GOOD_MAX) return 100;

  if (t < GOOD_MIN) {
    float ratio = (t - HARD_MIN) / (GOOD_MIN - HARD_MIN);
    return 100 * ratio;
  } else {  // t > GOOD_MAX && t < HARD_MAX
    float ratio = (HARD_MAX - t) / (HARD_MAX - GOOD_MAX);
    return 100 * ratio;
  }
}

// 湿度舒适度：40–55% 最佳，55–65 一般，>65 不适
float scoreHumidity(float h) {
  const float HARD_MIN = 20;
  const float GOOD_MIN = 40;
  const float GOOD_MAX = 55;
  const float HARD_MAX = 75;

  if (h <= HARD_MIN || h >= HARD_MAX) return 0;
  if (h >= GOOD_MIN && h <= GOOD_MAX) return 100;

  if (h < GOOD_MIN) {
    float ratio = (h - HARD_MIN) / (GOOD_MIN - HARD_MIN);
    return 100 * ratio;
  } else {  // h > GOOD_MAX && h < HARD_MAX
    float ratio = (HARD_MAX - h) / (HARD_MAX - GOOD_MAX);
    return 100 * ratio;
  }
}

// 空气质量评分（MKR 是 12bit ADC，0~4095，阈值按 UNO 版放大约 4 倍）
// 这里先给一个大概范围，之后你可以根据实际 MQ135 的 baseline 再调
float scoreAirQuality(int mqRaw) {
  const float HARD_MIN = 400;   // 理论较干净时下限
  const float GOOD_MIN = 600;   // 很干净
  const float GOOD_MAX = 1040;  // 普通宿舍
  const float HARD_MAX = 2000;  // 很差 / 有烟雾/喷雾

  if (mqRaw <= GOOD_MIN) return 100;
  if (mqRaw >= HARD_MAX) return 0;

  if (mqRaw <= GOOD_MAX) {
    // GOOD_MIN~GOOD_MAX: 100 → 80
    float ratio = (mqRaw - GOOD_MIN) / (GOOD_MAX - GOOD_MIN);
    return 100 - 20 * ratio;
  } else {
    // GOOD_MAX~HARD_MAX: 80 → 0
    float ratio = (mqRaw - GOOD_MAX) / (HARD_MAX - GOOD_MAX);
    return 80 * (1.0 - ratio);
  }
}

// 综合舒适度（Chow Chow Comfort Index）：0~100
float computeComfortIndex(float tempScore, float humScore,
                          float airScore, float noiseScore) {
  // 温湿度权重大一点，空气和噪音次之
  return 0.30 * tempScore
         + 0.30 * humScore
         + 0.20 * airScore
         + 0.20 * noiseScore;
}

// ========== 3. Neopixel 显示（带“电流保护”设计） ==========

// 舒适度 0~100 → 亮灯个数 0~NUM_PIXELS
int comfortToLedCount(float comfort) {
  int n = (int)round(comfort / 100.0 * NUM_PIXELS);
  if (n < 0) n = 0;
  if (n > NUM_PIXELS) n = NUM_PIXELS;
  return n;
}

// 舒适度 → 颜色（使用低饱和度防止电流过大）
uint32_t comfortToColor(float comfort) {
  // 70~100: 绿色   (0, 80, 0)
  // 40~70 : 黄色   (80, 50, 0)
  // 0~40  : 红色   (80, 0, 0)
  if (comfort >= 70) {
    return strip.Color(0, 80, 0);
  } else if (comfort >= 40) {
    return strip.Color(80, 50, 0);
  } else {
    return strip.Color(80, 0, 0);
  }
}

// 把舒适度显示在灯条上（左边亮，右边灭）
void showComfortOnStrip(float comfort) {
  int count = comfortToLedCount(comfort);
  uint32_t col = comfortToColor(comfort);

  for (int i = 0; i < NUM_PIXELS; i++) {
    if (i < count) {
      strip.setPixelColor(i, col);
    } else {
      strip.setPixelColor(i, 0);
    }
  }
  strip.show();
  lastLedActiveTime = millis();
}

// 熄灭所有灯（自动休眠用）
void turnOffStrip() {
  for (int i = 0; i < NUM_PIXELS; i++) {
    strip.setPixelColor(i, 0);
  }
  strip.show();
}

// ========== 4. e-paper 显示 ==========

void epaperInit() {
  display.init(115200);    // Waveshare 推荐波特率
  display.setRotation(1);  // 竖屏方向最正确
  display.setFullWindow();
  display.setTextColor(GxEPD_BLACK);
}
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

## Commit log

2025-11-27 Arduino sketch for testing all the sensors
    An Arduino sketch that reads VOC, humidity, and sound sensors to calculate a dog comfort index and displays status via NeoPixel LEDs. Includes sensor initialization, weighted scoring, and color logic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
2025-12-03 Add circuit diagram images
    Added three previous circuit diagram images: circuit-v1.jpg, circuit-v2.jpg, and circuit-v2.1.jpg to the media directory for documentation or reference purposes.
2025-12-10 Add enhanced V4 dorm pet monitor and reorganize files
    Added 0016_v4/0016_v4.ino with advanced air quality, noise, and comfort monitoring for pet dorms using Arduino MKR WiFi 1010. Moved 0016_cw_v2.ino into a subfolder, updated .DS_Store files, and added a related PowerPoint presentation.
    [0016_cw_v2.ino, 0016_v4.ino]
2026-01-12 Add final version and reorganize project files
    Added 0016_final_version.ino and reorganized previous versions into subfolders. Included new 3D model STL files and updated media assets for E-paper display and circuit images. This improves project 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
    [mypj_cover.stl, mypj_v2botttom.stl, mypj_v2lid.stl]
2026-01-12 Add media assets for documentation
    Added several PNG images to the media directory, including circuit diagrams, code examples, and enclosure visuals, to support project documentation and improve clarity.
2026-01-12 Add case and dog images to media directory
    Added two new image files, case.png and dog.png, to the media directory for use in the project.
2026-01-12 Enhance README with comprehensive project details
    Updated README.md with additional details on system architecture, sensors, safety override, feedback layers, evaluation, achievements, limitations, future roadmap, references, and generative AI use.
